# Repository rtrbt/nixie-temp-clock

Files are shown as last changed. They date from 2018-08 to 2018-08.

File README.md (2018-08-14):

# nixie-temp-clock
A modular nixie clock and thermometer based on [Exixe](https://github.com/dekuNukem/exixe).
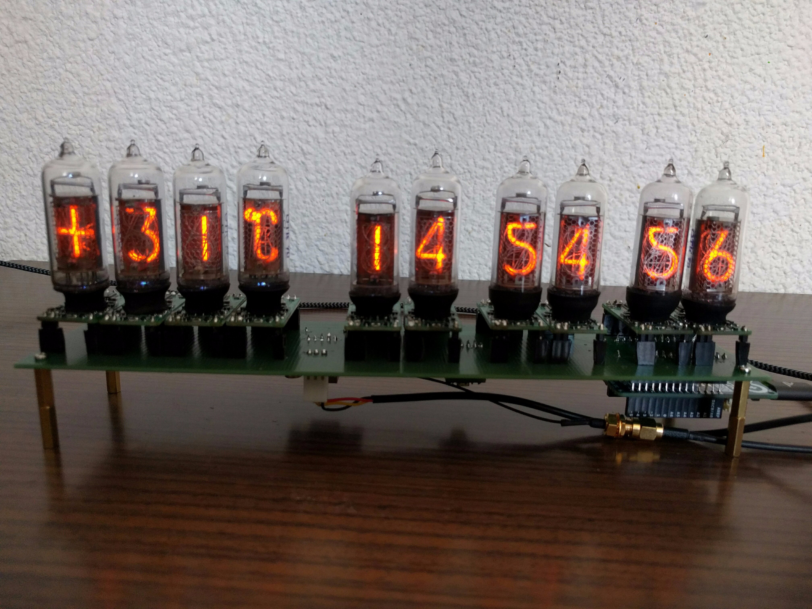
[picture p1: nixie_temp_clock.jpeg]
The finished clock


## Features
- Shows temperature (in °C) and GPS-synchronized time
- Completely modular: the PCB only connects all modules via pin headers

## Hardware
To build your own you need:
- The PCB
- Ten Exixe modules
- One IN-19A, one IN-19V and eight IN-14 tubes
- A high-voltage power supply, as the nixies need 180V to glow. Has to be pin-compatible to [this one](https://www.ebay.com/itm/322511957768)
- A DS18B20 temperature sensor
- A GPS module which communicates via I²C, I recommend [this one](https://www.sparkfun.com/products/14414).
- An Arduino or compatible board in the MKR form factor, for example the Arduino MKR Zero

## Software
The Arduino sketch and required files can be found in the firmware folder. If you define USE_SERIAL, the Arduino will report errors raised during setup. Also it will report if the main loop took longer than 33ms, which would slow down the cross-fade effect.

## TODO
- Find some use for the tube back light (maybe temperature dependant?)
- Find some use for the MKR Zero's microSD slot
- Periodically display the current date (cross-fade)
- Build a case
- Add some buttons
- Maybe add another temperature sensor
- Port the board schematic from EAGLE to KiCad, also add a silk screen layer

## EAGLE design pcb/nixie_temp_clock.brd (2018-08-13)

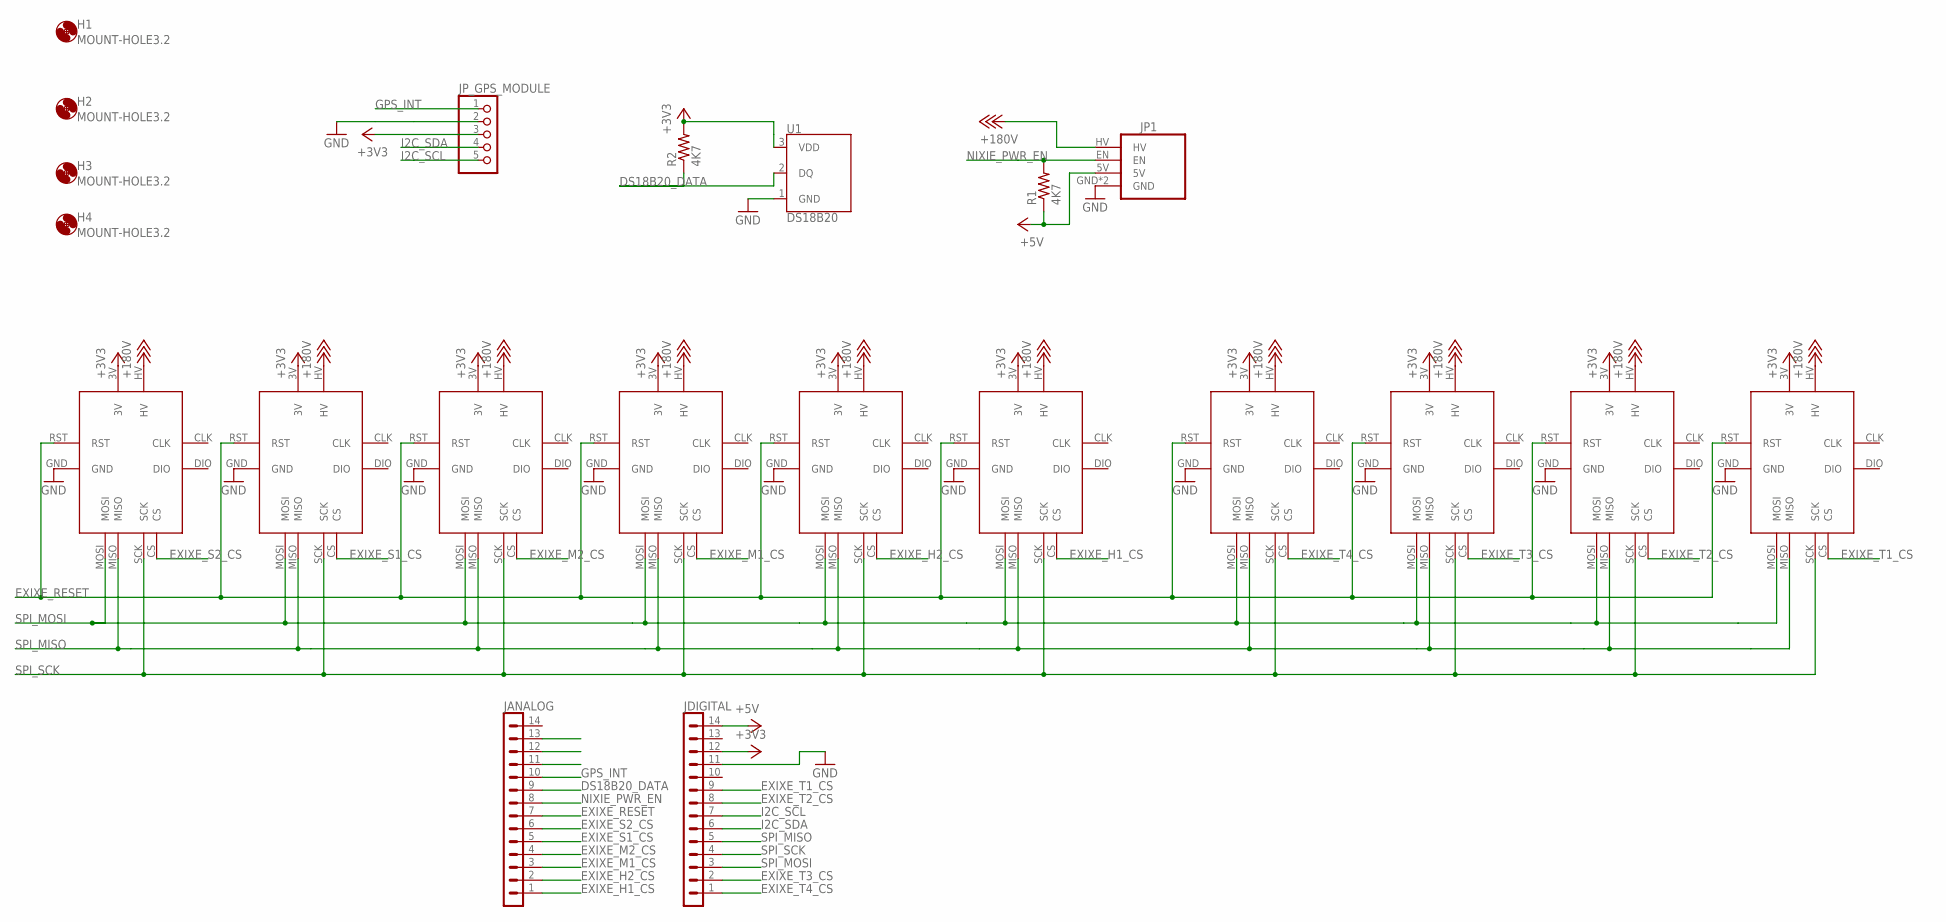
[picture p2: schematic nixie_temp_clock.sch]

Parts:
EXIXE_H1, EXIXE_H2: EXIXE_MODULE_EXIXE; EXIXE_MODULE_EXIXE_PAC
EXIXE_M1, EXIXE_M2: EXIXE_MODULE_EXIXE; EXIXE_MODULE_EXIXE_PAC
EXIXE_S1, EXIXE_S2: EXIXE_MODULE_EXIXE; EXIXE_MODULE_EXIXE_PAC
EXIXE_T1, EXIXE_T2, EXIXE_T3, EXIXE_T4: EXIXE_MODULE_EXIXE; EXIXE_MODULE_EXIXE_PAC
H1, H2, H3, H4: MOUNT-HOLE3.2; 3,2
JANALOG: ARDUINO-CONNECTORS_PINHD-1X14-SMTH; ARDUINO-CONNECTORS_1X14
JDIGITAL: ARDUINO-CONNECTORS_PINHD-1X14-SMTH; ARDUINO-CONNECTORS_1X14
JP1: EBAY_MODULETAOBAO; TAOBAO_PKG
JP_GPS_MODULE: PINHD-1X5; 1X05
R1, R2: 4K7; 0207/15
U1: DS18B20; TO-92-AMMO

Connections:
+3V3: EXIXE_H1.3V, EXIXE_H2.3V, EXIXE_M1.3V, EXIXE_M2.3V, EXIXE_S1.3V, EXIXE_S2.3V, EXIXE_T1.3V, EXIXE_T2.3V, EXIXE_T3.3V, EXIXE_T4.3V, JDIGITAL.12, JP_GPS_MODULE.3, R2.2, U1.3 (VDD)
+5V: JDIGITAL.14, JP1.5V, R1.1
+180V: EXIXE_H1.HV, EXIXE_H2.HV, EXIXE_M1.HV, EXIXE_M2.HV, EXIXE_S1.HV, EXIXE_S2.HV, EXIXE_T1.HV, EXIXE_T2.HV, EXIXE_T3.HV, EXIXE_T4.HV, JP1.HV
DS18B20_DATA: JANALOG.9, R2.1, U1.2 (DQ)
EXIXE_H1_CS: EXIXE_S2.CS, JANALOG.1
EXIXE_H2_CS: EXIXE_S1.CS, JANALOG.2
EXIXE_M1_CS: EXIXE_M2.CS, JANALOG.3
EXIXE_M2_CS: EXIXE_M1.CS, JANALOG.4
EXIXE_RESET: EXIXE_H1.RST, EXIXE_H2.RST, EXIXE_M1.RST, EXIXE_M2.RST, EXIXE_S1.RST, EXIXE_S2.RST, EXIXE_T1.RST, EXIXE_T2.RST, EXIXE_T3.RST, EXIXE_T4.RST, JANALOG.7
EXIXE_S1_CS: EXIXE_H2.CS, JANALOG.5
EXIXE_S2_CS: EXIXE_H1.CS, JANALOG.6
EXIXE_T1_CS: EXIXE_T4.CS, JDIGITAL.9
EXIXE_T2_CS: EXIXE_T3.CS, JDIGITAL.8
EXIXE_T3_CS: EXIXE_T2.CS, JDIGITAL.2
EXIXE_T4_CS: EXIXE_T1.CS, JDIGITAL.1
GND: EXIXE_H1.GND, EXIXE_H2.GND, EXIXE_M1.GND, EXIXE_M2.GND, EXIXE_S1.GND, EXIXE_S2.GND, EXIXE_T1.GND, EXIXE_T2.GND, EXIXE_T3.GND, EXIXE_T4.GND, JDIGITAL.11, JP1.GND, JP1.GND2 (GND), JP_GPS_MODULE.2, U1.1 (GND)
GPS_INT: JANALOG.10, JP_GPS_MODULE.1
I2C_SCL: JDIGITAL.7, JP_GPS_MODULE.5
I2C_SDA: JDIGITAL.6, JP_GPS_MODULE.4
NIXIE_PWR_EN: JANALOG.8, JP1.EN, R1.2
SPI_MISO: EXIXE_H1.MISO, EXIXE_H2.MISO, EXIXE_M1.MISO, EXIXE_M2.MISO, EXIXE_S1.MISO, EXIXE_S2.MISO, EXIXE_T1.MISO, EXIXE_T2.MISO, EXIXE_T3.MISO, EXIXE_T4.MISO, JDIGITAL.5
SPI_MOSI: EXIXE_H1.MOSI, EXIXE_H2.MOSI, EXIXE_M1.MOSI, EXIXE_M2.MOSI, EXIXE_S1.MOSI, EXIXE_S2.MOSI, EXIXE_T1.MOSI, EXIXE_T2.MOSI, EXIXE_T3.MOSI, EXIXE_T4.MOSI, JDIGITAL.3
SPI_SCK: EXIXE_H1.SCK, EXIXE_H2.SCK, EXIXE_M1.SCK, EXIXE_M2.SCK, EXIXE_S1.SCK, EXIXE_S2.SCK, EXIXE_T1.SCK, EXIXE_T2.SCK, EXIXE_T3.SCK, EXIXE_T4.SCK, JDIGITAL.4

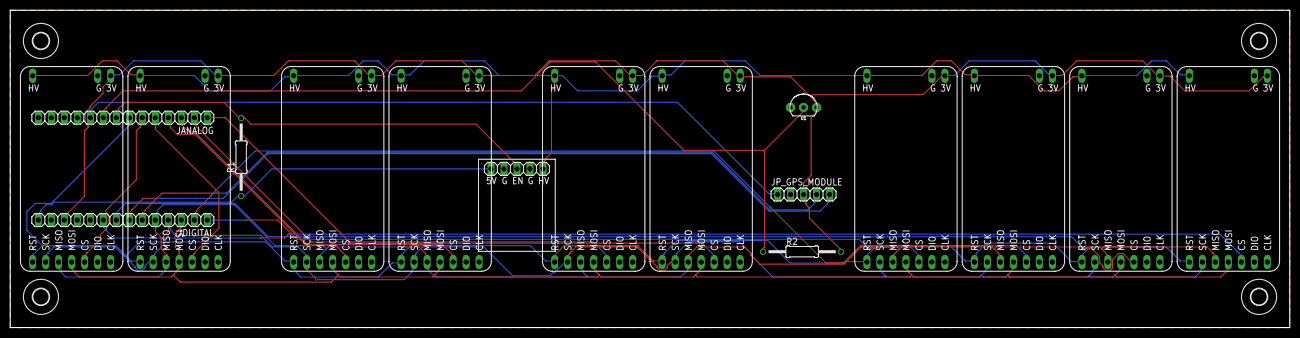
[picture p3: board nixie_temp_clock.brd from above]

Board: 2 copper layers, 250.0 x 62.0 mm, 21 parts (0 on the bottom side), 23 nets.

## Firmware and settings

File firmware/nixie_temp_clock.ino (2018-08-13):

#include <climits>

#include <Time.h>
#include <Timezone.h>
#include "timezones.h"
#include "exixe_component.h"
#include "temp_component.h"
#include "gps_component.h"

Timezone *selected_timezone = &timezones::CE;

//#define USE_SERIAL

const auto TEMP_DATA_PIN = A4;

exixe_component nixies;
temp_component temp_sensor{TEMP_DATA_PIN};
gps_clock_component gps_clock;

void setup()
{
#ifdef USE_SERIAL
    Serial.begin(9600);
    Serial.println("Starting setup");
#endif
    if(!nixies.setup())
    {
#ifdef USE_SERIAL
            Serial.println("Could not initialize exixe boards!");
#endif
            while(true)
                    delay(1000);
    }
    nixies.report_setup_progress(1/3);
    
    if(!temp_sensor.setup())
    {
#ifdef USE_SERIAL
            Serial.println("Could not initalize temperature sensor!");
#endif
            nixies.report_setup_error_and_exit();
    }
    nixies.report_setup_progress(2/3);
    
    if(!gps_clock.setup())
    {
#ifdef USE_SERIAL
            Serial.println("Could not initialize GPS!");
#endif
            nixies.report_setup_error_and_exit();
    }
    nixies.report_setup_progress(1);
    nixies.report_setup_progress(0); //disable dots
}


unsigned long sub_millis(unsigned long start, unsigned long end)
{
    if(end >= start)
        return end - start;

    //handle overflow
    auto start_to_overflow = ULONG_MAX - start;
    return end + start_to_overflow;
}


void loop()
{ 
    static bool timeWasSet = false;
    auto start = millis();
    
    auto temp = temp_sensor.loop();
    auto t = gps_clock.loop(selected_timezone);
    if(t != 0)
    {
      setTime(t);
      timeWasSet = true;
    }

    if(timeWasSet)
      nixies.loop(hour(), minute(), second(), temp);
    else
      nixies.loop(0,0,0, temp);
    
    auto runtime = sub_millis(start, millis());
    if(runtime < 33)
        delay(33 - runtime);
#ifdef USE_SERIAL 
    else
    {
        Serial.print("loop runtime was longer than 33ms: ");
        Serial.print(runtime);
        Serial.println("ms");
    }
#endif    
}

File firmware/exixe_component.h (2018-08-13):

#pragma once

#include <Arduino.h>
#include <exixe.h>

const auto NIXIE_PWR_EN = A5;
const auto EXIXE_RESET = A6;

const auto EXIXE_H1_CS = 5;
const auto EXIXE_H2_CS = 4;
const auto EXIXE_M1_CS = 3;
const auto EXIXE_M2_CS = 2;
const auto EXIXE_S1_CS = 1;
const auto EXIXE_S2_CS = 0;
const auto EXIXE_T1_CS = 14;
const auto EXIXE_T2_CS = 13;
const auto EXIXE_T3_CS = 7;
const auto EXIXE_T4_CS = 6;

const decltype(EXIXE_H1_CS) exixe_cs_pins[10] = {
        EXIXE_H1_CS,
        EXIXE_H2_CS,
        EXIXE_M1_CS,
        EXIXE_M2_CS,
        EXIXE_S1_CS,
        EXIXE_S2_CS,
        EXIXE_T1_CS,
        EXIXE_T2_CS,
        EXIXE_T3_CS,
        EXIXE_T4_CS
};

const auto tube_count = sizeof(exixe_cs_pins) / sizeof(exixe_cs_pins[0]);

class exixe_component
{
public:
    bool setup();

    void report_setup_progress(float progress);

    void report_setup_error_and_exit();

    void loop(int hour, int minute, int second, float temperature);

private:
    void show_two_digits(int num, int tensNixieIdx, int onesNixieIdx);

    float temperature;
    exixe *nixies;
};

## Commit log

2018-08-13 Added arduino firmware.
2018-08-13 Added board schematic.
    [nixie_temp_clock.brd, nixie_temp_clock.sch]

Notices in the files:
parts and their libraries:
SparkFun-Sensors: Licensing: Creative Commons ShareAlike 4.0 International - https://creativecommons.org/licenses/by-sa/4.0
